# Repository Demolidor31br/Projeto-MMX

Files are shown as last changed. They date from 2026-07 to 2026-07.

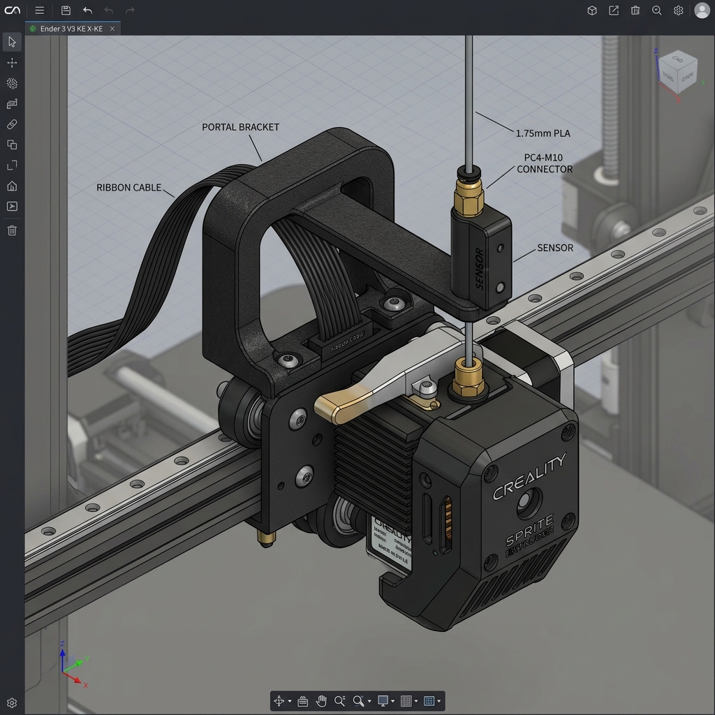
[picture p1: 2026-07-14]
suporte_sensor_montado.jpg

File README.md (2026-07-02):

# Projeto MMX Ender 3 V3 KE

Repositório para o desenvolvimento, configuração e documentação da instalação do sistema **MMX** (Multi-Material Extension / Upgrade) na impressora 3D **Ender 3 V3 KE** (rodando firmware Klipper).

## ⚙️ Especificações Técnicas e Hardware
- **Kit Adquirido:** Trianglelab MMX - **Set B** (Com placa de controle EBB42, sem peças impressas, sem buffer de filamento FV3).
- **Eletrônica de Controle:** Placa **BigTreeTech EBB42** (CAN/USB). Será conectada via USB diretamente no host Klipper (Nebula Pad da Ender 3 V3 KE, que possui root liberado).
- **Software/Firmware:** Ecossistema **Happy Hare** para Klipper (o MMX possui suporte nativo total ao Happy Hare v2/v3).
- **Buffer de Filamento:** Como o kit não acompanha o buffer FV3, usaremos o sistema **Carrot Patch** (ou similar) que serve tanto de suporte de bobinas quanto de buffer passivo, ou fabricaremos um sistema próprio.
- **Peças Impressas:** As peças do MMX precisam ser impressas em ABS/ASA/PETG antes da montagem física na impressora.
- **Montagem Física:** A impressora é uma Creality Ender 3 V3 KE (frame de pórtico padrão, sem perfis 2020 abertos como na Voron). O suporte físico para prender o MMX no topo ou na lateral da KE precisará ser adaptado/desenhado (suporte genérico).

## 🚀 Objetivos do Projeto
- Impressão das peças estruturais do MMX.
- Montagem física e fixação do MMX no pórtico da Ender 3 V3 KE.
- Fiação elétrica da placa EBB42 com a fonte/Nebula Pad.
- Instalação e calibração do **Happy Hare** no Klipper da impressora.
- Configuração de macros de troca de ferramenta (Toolchange) e sensores.

## 👥 Colaboradores
- @Demolidor31br (Criador)
- @cursoscommatheus-oss (Colaborador)

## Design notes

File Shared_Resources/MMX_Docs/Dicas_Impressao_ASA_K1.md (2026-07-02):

# Guia de Calibração e Impressão de ASA na Creality K1

Este guia contém as melhores práticas e calibrações recomendadas para imprimir as peças do **MMX** utilizando filamento **Bambu ASA** na sua **Creality K1** (com CFS).

---

## 1. Parâmetros Adaptados para a K1 no Perfil
O perfil que geramos já leva em consideração as limitações físicas e térmicas da K1 para materiais de alta temperatura (ASA):
- **Limite de Vazão Volumétrica (Max Volumetric Speed):** Limitado em `12 mm³/s`. Embora o bico da K1 consiga derreter até `24 mm³/s` de PLA, o ASA precisa de mais tempo de residência no bloco térmico para derreter de forma homogênea. Limitar a vazão garante que o fatiador nunca force velocidades que causem entupimentos ou peças frágeis.
- **Velocidade de Impressão:** Reduzida para `120 mm/s` (paredes externas) e `150 mm/s` (paredes internas). Velocidades muito altas em ASA diminuem drasticamente a adesão entre camadas, fazendo a peça quebrar fácil. Além disso, velocidades mais baixas garantem **precisão dimensional**, crucial para encaixar os rolamentos, eixos e o servo do MMX.
- **Controle de Ventoinhas:**
  - Ventoinha da Peça (Part Cooling Fan): Mínimo `10%` / Máximo `20%` (apenas para balanços/pontes).
  - Ventoinha Auxiliar Lateral (Aux Fan): **Desligada (0%)**. O fluxo direto dessa ventoinha causaria encolhimento rápido da peça (*warping*) e descolamento da mesa.
  - Ventoinha de Exaustão Traseira: `60%` para filtrar o ar com o filtro de carvão ativado sem resfriar a câmara.

---

## 2. Calibrações Recomendadas (Antes de Iniciar as Peças do MMX)
O Creality Print (por usar a base do OrcaSlicer) possui um menu de **Calibração** no topo. Antes de imprimir as peças finais, recomendamos rodar dois testes simples para o filamento Bambu ASA:

### A. Calibração de Vazão (Flow Rate)
O fluxo padrão está em `0.95` (95%), que é excelente para o ASA. Se quiser a precisão perfeita:
1. No topo do Creality Print, vá em **Calibração** ➔ **Vazão (Flow Rate)**.
2. Siga o Passo 1 (Pass 1) e imprima o padrão.
3. Escolha o quadrado com a superfície mais lisa e ajuste o multiplicador no perfil.

### B. Calibração de Pressure Advance (PA)
O Pressure Advance evita que falte filamento no início de uma linha e que ocorra excesso (cantos arredondados) no final de movimentos rápidos. Para o ASA na K1, o valor ideal costuma ficar entre `0.035` e `0.045`.
1. Vá em **Calibração** ➔ **Pressure Advance**.
2. Selecione a opção **Linha (Line)** ou **Torre (Tower)**.
3. Após a impressão, verifique qual linha ficou mais uniforme nas transições de velocidade e configure o valor no perfil do filamento (seção de Extrusora/Pressure Advance).

---

## 3. Dicas de Ouro para Sucesso com ASA na K1
- **Pré-aquecimento da Câmara (Crucial):** O segredo para o ASA não empenar é a temperatura interna do ar (câmara). Antes de iniciar a impressão, aqueça a mesa a `100 °C` manualmente e deixe a impressora fechada por **10 a 15 minutos**. Isso vai elevar a temperatura da câmara acima de `45-50 °C`, eliminando o risco de trincas (*delamination*).
- **Adesão na Mesa:** Use a mesa de PEI lisa (Smooth PEI) limpa com Álcool Isopropílico. Aplique uma camada fina de cola bastão (ou spray fixador como 3DLac/Karina) para servir de interface de descolamento (o ASA pode grudar demais no PEI e rasgar a chapa ao esfriar, a cola serve como proteção e facilitador de remoção).
- **Suportes:** Algumas peças do MMX possuem balanços. Use suporte do tipo **Tree (Slim)** ou **Normal** com distância Z do suporte de `0.2mm` para facilitar a remoção.

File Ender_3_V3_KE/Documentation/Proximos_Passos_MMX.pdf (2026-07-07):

# PROJETO MMX: MULTI-MATERIAL

## Upgrade de Impressão 3D para Ender 3 V3 KE

## Guia Técnico e Próximos Passos de Execução

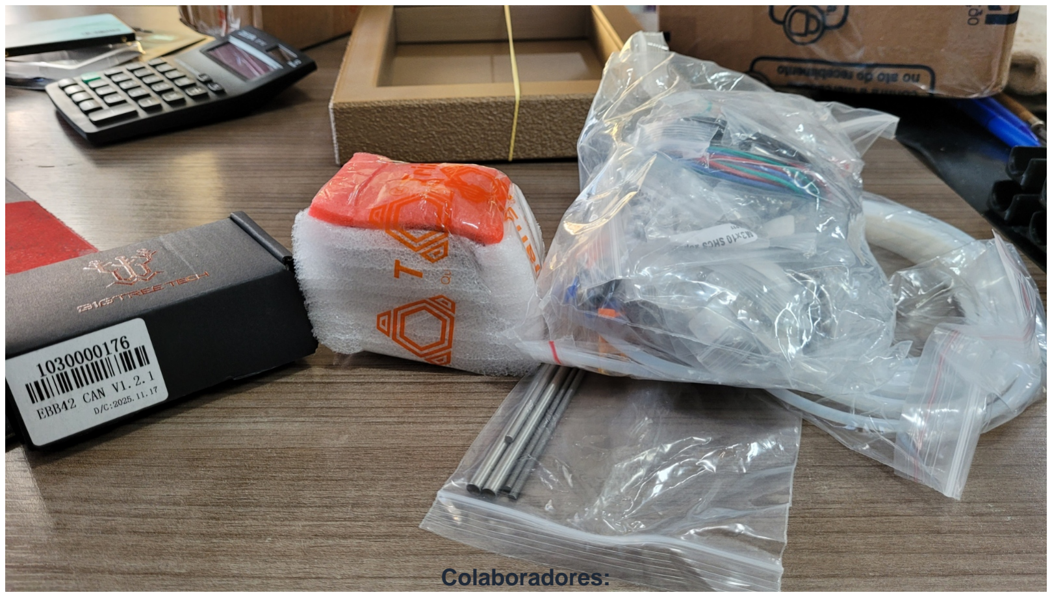
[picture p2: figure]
Colaboradores:

Criador do Projeto: @Demolidor31br Colaborador Técnico: @cursoscommatheus-oss

Gerado em Julho de 2026

Projeto MMX - Ender 3 V3 KE | Guia de Execução | Engenharia & Configuração

## 1. Introdução ao Projeto

Este guia prático foi elaborado para orientar os passos de integração do sistema multicor MMX (Trianglelab Set
B) na impressora Creality Ender 3 V3 KE, utilizando a placa controladora BigTreeTech EBB42 v1.2.1 ligada via USB direta. Com as peças sendo impressas em filamento ASA de alta temperatura na K1, o foco agora muda para o fluxo de montagem mecânica, fiação, compilação de firmware e calibração fina.

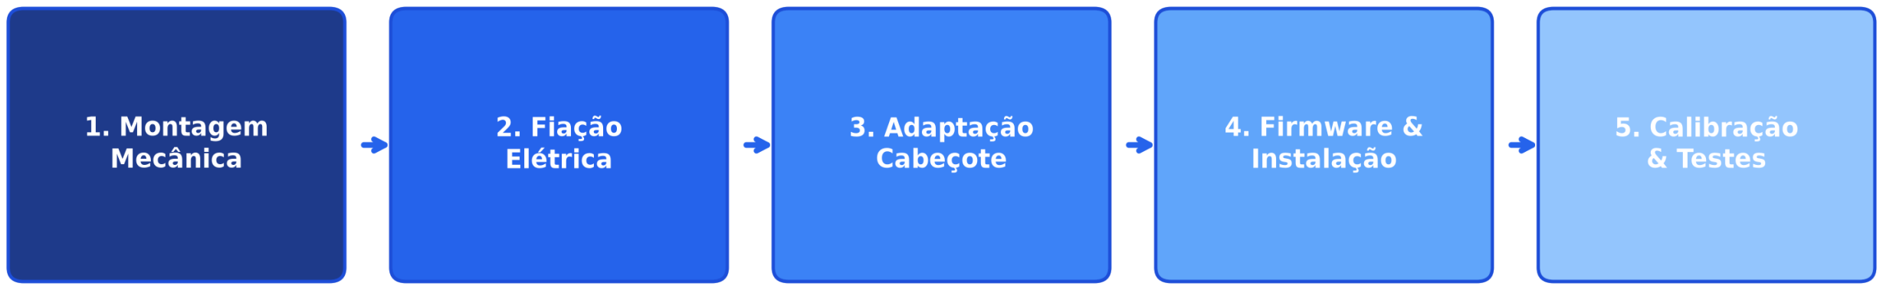
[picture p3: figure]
2. Visão Geral do Fluxo de Trabalho

Abaixo está o roteiro de execução em 5 etapas para colocar o sistema MMX em pleno funcionamento:

[NOTE] Isolamento de Falhas
Siga rigorosamente a ordem proposta. Não avance para a calibração de software sem certificar-se de que a fiação física e a montagem mecânica do seletor de cames estão perfeitas e sem atritos.
Documento de Engenharia - Uso Interno e Colaborativo | Página 2

## 3. Passo 1: Montagem Mecânica do MMX

Após concluir a impressão das peças em ASA/PETG, a montagem física deve seguir esta ordem:

1. Preparação das Laterais: Limpe e lixe rebarbas das peças estruturais (mmx-left-side e mmx-right-side) para garantir encaixes perfeitos.
2. Rolamentos e Eixos: Insira os rolamentos 608 e 625 nos alojamentos correspondentes e monte o eixo de tração central com as engrenagens duplas Bondtech (BMG).
3. Montagem das Idler Doors: Encaixe as 4 portas de pressão dos roletes de filamento (numeradas de 0 a 3). Certifique-se de que cada porta se movimenta livremente sem travar lateralmente.
4. Sistema de Cames e Servo: Monte o eixo de cames (camshaft) com a polia T36 no servo motor e a engrenagem T80 com a correia fechada GT2. O ajuste fino da tensão da correia evita folgas.
5. Gaveta de Eletrônica: Monte a gaveta deslizante na base do MMX para acomodar a placa EBB42 e o step-down de energia.

[WARNING] Folga Dimensional das Portas
Se as portas de pressão (idler doors) apresentarem atrito ao girar em torno do eixo, realize um leve lixamento nas laterais. Elas devem cair livremente sob a força da gravidade.
Documento de Engenharia - Uso Interno e Colaborativo | Página 3

## 4. Passo 2: Fiação Elétrica e Conexões (EBB42 v1.2.1)

A placa EBB42 v1.2.1 ficará oculta na base do MMX e comandará todos os atuadores e sensores. Siga o mapeamento elétrico abaixo para conectar os cabos de forma organizada:

- Motor de Passo Nema 14 (Gear): Conecte na porta de motor (TMC2209).
- Servo Motor (Camshaft): Ligue o fio de sinal de controle (geralmente amarelo/laranja) no pino PB9 da porta Probe.
- Alimentação do Servo: O positivo (V+) e negativo (GND) do servo devem ser alimentados pelo módulo Step-Down ajustado para 5.0V ou 6.0V. O GND do step-down deve ser unificado ao GND da placa EBB42.

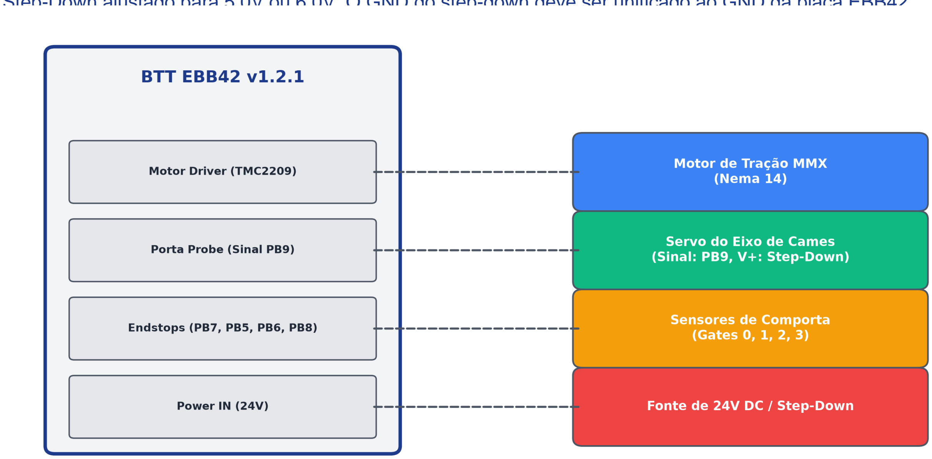
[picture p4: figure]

- Sensores Pre-gate (Portas 0 a 3): Conecte os sensores ópticos de filamento de cada comporta nas portas de endstop (PB7, PB5, PB6 e PB8 respectivamente).

[WARNING] Alimentação do Servo
Nunca alimente o positivo do servo motor diretamente pelo pino de 5V da EBB42. O pico de corrente do servo causará queda de tensão na placa, fazendo o microcontrolador travar e abortar a impressão.
Documento de Engenharia - Uso Interno e Colaborativo | Página 4

## 5. Passo 3: Adaptação do Cabeçote da Ender 3 V3 KE

Como a Ender 3 V3 KE utiliza uma extrusora Direct Drive leve, são necessárias duas modificações físicas:

1. Realocação do Sensor de Filamento: Imprima a nova carcaça do cabeçote e mova o sensor óptico original para ficar posicionado o mais próximo possível das engrenagens de tração. Isso assegura que o Klipper saiba o momento exato em que a ponta do filamento é engatada pela extrusora.
2. Montagem do Y-Splitter: Instale o divisor flutuante (4 entradas para 1 saída) logo acima do sensor realocado. Passe os 4 tubos PTFE Capricorn de diâmetro interno menor (2.0mm) do MMX até as entradas do Y-Splitter.

## 6. Passo 4: Compilação e Instalação do Firmware

1. SSH no Nebula Pad: Conecte via SSH e compile o Klipper para o chip da EBB42:
- Micro-controller: STMicroelectronics STM32
- Processor: STM32G0B1
- Bootloader offset: 8KiB bootloader
- Communication interface: USB (on PA11/PA12)
2. Flash da Placa: Transfira o 'klipper.bin' gerado para o Windows, conecte a placa segurando BOOT e utilize o STM32CubeProgrammer para gravar no endereço 0x08002000.
3. Happy Hare: Clone e execute o script de instalação ('./install.sh'). Escolha o tipo de MMU como 'Ercf' e selecione a placa controladora correspondente 'BTT EBB 42 CANbus v1.2' para mapear os pinos.
Documento de Engenharia - Uso Interno e Colaborativo | Página 5

## 7. Passo 5: Calibração das Macros no Klipper

Com todos os componentes mecânicos e eletrônicos no lugar, faça a calibração de software:

1. Identificação do ID USB:
No SSH da impressora, obtenha o ID do dispositivo USB:
$ ls /dev/serial/by-id/
Copie o ID retornado e configure a seção [mcu mmu] no arquivo mmu_hardware.cfg.
2. Calibração do Seletor (Eixo de Cames):
O Happy Hare precisa saber os ângulos exatos do servo motor para engatar cada canal.
Execute o comando abaixo, alterando X para o ângulo do servo (entre 0 e 180):
$ MMU_CALIBRATE_SELECTOR ANGLE=X SAVE=0
Quando encontrar o ângulo ideal no qual o cames empurra a idler door do canal selecionado e engata a engrenagem, anote e salve nas configurações.
3. Calibração do Feeder (Tração MMX):
Use a macro de calibração para garantir que o motor de passo traciona exatamente 100mm de filamento:
$ MMU_CALIBRATE_GEAR
4. Calibração do Bowden (PTFE):
Calibre a distância percorrida pelo filamento da saída do MMX até a entrada do Y-Splitter:
$ MMU_CALIBRATE_BOWDEN
5. Calibração de Tip Shaping (Formação da Ponta):
Ajuste as velocidades de retração e resfriamento no Happy Hare para moldar a ponta do filamento de modo a não criar fiapos finos que possam causar entupimentos durante a troca de ferramentas.

[NOTE] Apoio da Comunidade
As calibrações de ângulos do eixo de cames do MMX são únicas para cada montagem mecânica. Faça testes com calma em cada canal (0, 1, 2 e 3) antes de rodar impressões de longa duração.
Documento de Engenharia - Uso Interno e Colaborativo | Página 6

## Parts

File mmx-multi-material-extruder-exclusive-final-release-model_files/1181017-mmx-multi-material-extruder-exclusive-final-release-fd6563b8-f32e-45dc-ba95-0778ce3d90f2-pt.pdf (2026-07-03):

MMX Multi-Material Extruder - Manual Traduzido (PT)

# Extrusora Multi-Material MMX

Lançamento Final Exclusivo por Nadir @ CN3D

### 1. Resumo do Projeto

Este documento é a tradução oficial do manual de lançamento da extrusora multi-material MMX (Multi-Material Extruder) desenvolvida pela CN3D. O MMX é um sistema de MMU aberto, projetado para impressoras rodando Klipper, oferecendo alta personalização e suporte de hardware robusto.

Os criadores abriram oficialmente a solicitação de números de série para o MMX OG (versão padrão de 4 cores). Se você montou e colocou em funcionamento, pode registrar o seu número de série oficial no link: http://cn3d.eu/mmxserialrequest

### 2. Histórico de Atualizações de Peças

- 14/07/2025: As portas dos roletes de pressão (idler doors) foram feitas ligeiramente mais estreitas. Isso aumentou a folga de encaixe para evitar travamentos acidentais.
- 16/06/2025: Correção na polia do servo T36 (T36 Servo Pulley) no arquivo CAD. Se você usou a versão antiga do CAD, precisa reimprimir esta polia para ficar alinhada com o eixo de cames (camshaft).
- 12/06/2025: A bandeja inferior (bottom panel) foi atualizada para incluir espaço de encaixe de um módulo regulador de tensão (step down) e a bandeja da placa EBB.
- 03/04/2025: A engrenagem BMG nas portas dos roletes foi levemente recuada para garantir que engate somente quando o canal correspondente (comporta/gate) estiver ativo, evitando que gire em falso.

### 3. Principais Diferenciais do MMX

- Capacidade Personalizável: Embora o projeto padrão venha com 4 comportas (canais 0, 1, 2, 3), o sistema é modular e permite expandir ou reduzir o número de entradas conforme as suas necessidades.
- Confiabilidade Mecânica: Equipado com polias e correias em malha fechada GT2 de alta durabilidade e tensionadores ajustáveis, eliminando folgas e deslizamentos.
- Tração de Filamento Aprimorada: Utiliza engrenagens duplas padrão Bondtech (BMG) para uma pegada firme no filamento e uma alimentação suave.
- Recursos das Comportas: Cada canal possui um sensor de filamento individual e LEDs indicadores de status. Integrado nativamente com as macros do Happy Hare no Klipper, automatiza a carga e descarga sempre que o filamento entra no sensor.
- Modo Carretel Infinito (Endless Spool): Permite carregar várias bobinas do mesmo filamento. O Klipper muda automaticamente para o próximo canal quando o sensor detecta falta de filamento, evitando paradas de impressão tarde da noite.
- Mecânica Avançada de Servo e Cames: O eixo comando de cames (camshaft) é acionado por um servo com relação 36:20. Isso permite girar o eixo até 320 graus com apenas 180 graus de movimento do servo (aproximadamente 50 graus de movimento do servo por canal selecionado).

MMX Multi-Material Extruder - Manual Traduzido (PT)

### 4. Configurações de Impressão Recomendadas

- Materiais:
* Eixo de Cames (camshaft) e Portas dos roletes (idler doors): Imprimir em PLA ou PETG.
* Peças estruturais e carcaça geral: Imprimir em PETG, ABS ou ASA (Recomendado ASA para a K1).
- Altura de Camada: 0.20 mm.
- Perímetros (Walls): 4 voltas de parede.
- Camadas de Topo e Fundo (Top/Bottom): 5 camadas sólidas.
- Preenchimento (Infill): 15% a 20% (Nota de Calibração: Para uso mecânico pesado, a comunidade sugere subir para 40% Gyroid/Giroide).
- Suportes: Usar apenas no Eixo de Cames (camshaft) sob os ressaltos (cames). As portas dos roletes e outras peças planas não precisam de suporte.
- Orientações: Os arquivos STL baixados já estão orientados de fábrica na posição plana de impressão recomendada (separe-os no fatiador antes de organizar).

### 5. Índice de Arquivos do Printset

- Estruturais/Carcaça:
* mmx-left-side.stl / mmx-right-side.stl (Laterais principais)
* mmx-bottom-panel.stl / mmx-back-panel.stl / mmx-front-panel.stl (Painéis inferiores, traseiro e frontal)
- Transmissão/Movimento:
* mmx-camshaft.stl (Eixo comando de cames)
* mmx-t80.stl (Engrenagem T80)
* mmx-t36-servo-pulley.stl (Polia do Servo T36)
- Canais de Entrada (Gates):
* mmx-gate-x4.stl (Comportas de entrada)
* mmx-gate-spacer-x3.stl (Espaçadores entre comportas)
* mmx-idler-door-0, 1, 2, 3.stl (Portas dos roletes numeradas)
- Acessórios/Eletrônica:
* mmx-ebb-42-and-stepdown-slide-tray.stl (Gaveta da EBB42 e Step Down) * mmx-led-defuser-x4.stl (Difusores de LED)

### 6. Licenciamento do Projeto

Este projeto é de código aberto e está licenciado sob a Licença Pública Geral GNU v3.0 (GPL v3.0).
É permitida a criação de remixes, modificações e uso comercial, desde que mantida a atribuição original do autor (Nadir @ CN3D) e compartilhado sob a mesma licença open-source.

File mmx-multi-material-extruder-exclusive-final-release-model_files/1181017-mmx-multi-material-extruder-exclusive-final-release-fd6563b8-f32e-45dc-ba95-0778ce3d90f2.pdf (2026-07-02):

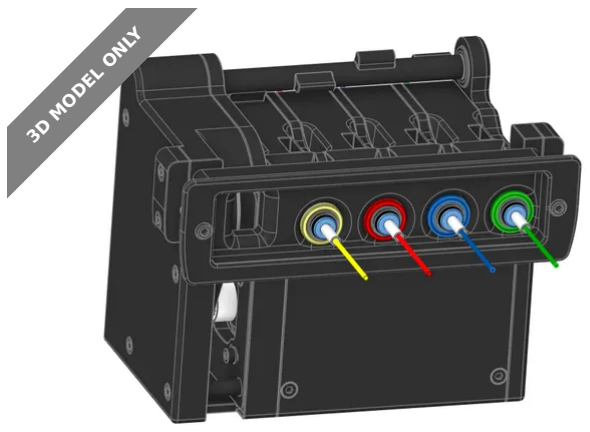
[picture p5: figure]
3D MODEL ONLY

## Summary

Beta release of MMX! Members get 2-week exclusive access. Join our Discord for BOM & updates:

3D Printers (https://printables.com/model?categoryId=1) > Other Printer Parts & Upgrades (https://printables.com/model?categoryId=2)

Tags: | spool | multimaterial | mmu | color | material | multi
prusammu | endless | mmx | pico | infinite | ams | cn3d
picommu | infinitespool | endlessspool | atipicommu

MMX OG — Serial Number Registration Now Open!

We’re officially opening serial number requests for the MMX OG (4-Color) Multi-Material Extruder.
If you’ve built one and made it work — this is your moment to make it official.

Each registered unit will receive a unique MMX Serial Number, as recognition for your work, dedication, and for bringing this community-driven system to life.
Not everyone who started the MMX journey finished it — so if you did, congratulations! You’ve earned your spot in the project’s history.

Nadir @ CN3D (https://printables.com/@Nadir)

## MMX Multi-Material Extruder – Exclusive Final Release

VIEW IN BROWSER (https://printables.com/model/1181017-mmx-multi-material-extruder-exclusive-final-releas)

updated 24. 10. 2025 | published 24. 10. 2025

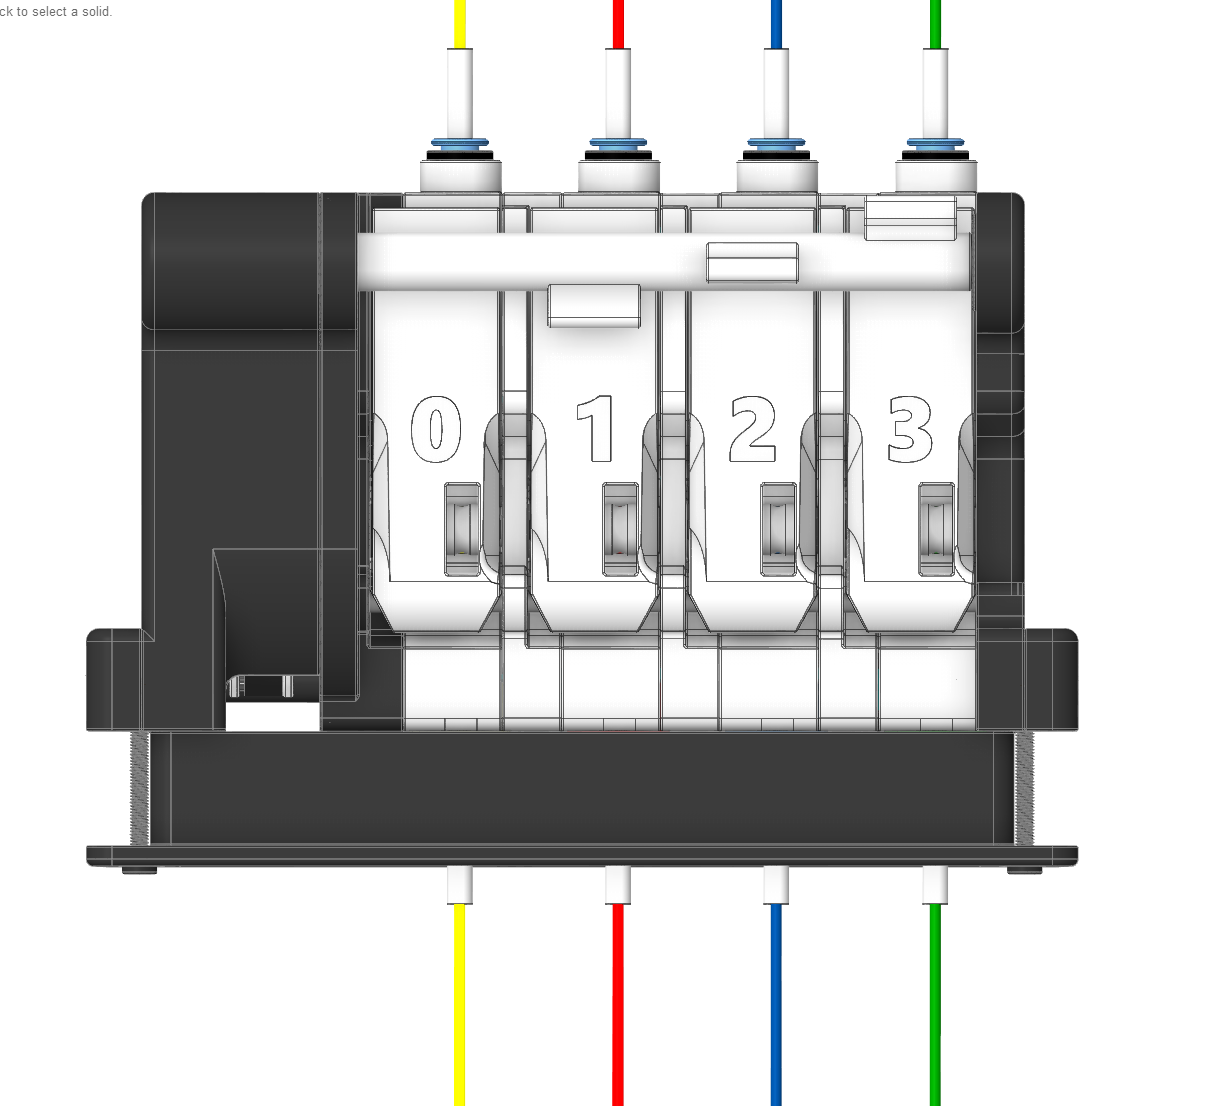
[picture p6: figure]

We have updated the model now the tray has a space for a step down so if you want to have the latest model download and reprint the bottom panel and the ebb tray
12-06-2025
you will need:

Check the download section there is a zip file that includes Orca

Register your build here:
http://cn3d.eu/mmxserialrequest

Thank you for trusting our design and being part of the CN3D community! Together we’re showing the world how far this maker movement can go.

We have made the idler doors a little bit narrow this way we have increased the gap where the idler door sits so it will not catch by mistake. 14-07-2025

We have updated the CAD it was a small err at the T36 Servo Pulley. only if you have used the one from the cad you have to reprint it! 16 - June - 2025
Also update the Right Side Cover.
Thanks to our member azlaeel for pointing this out

We can proudly announce that there is a kit available for purchase. The kit was tested, contains quality components and is all you need to build your MMX. You just have to download the files from here and print them.

The kit does not contain the 3d printed parts.

https://s.click.aliexpress.com/e/_EzjN06s

New update to the Camshaft and to the Idler doors that they are numbered to the specific locations.
also https://github.com/moggieuk/Happy-Hare added the MMX logo to the Mainsail PR and it's part of a new PR for Fluidd

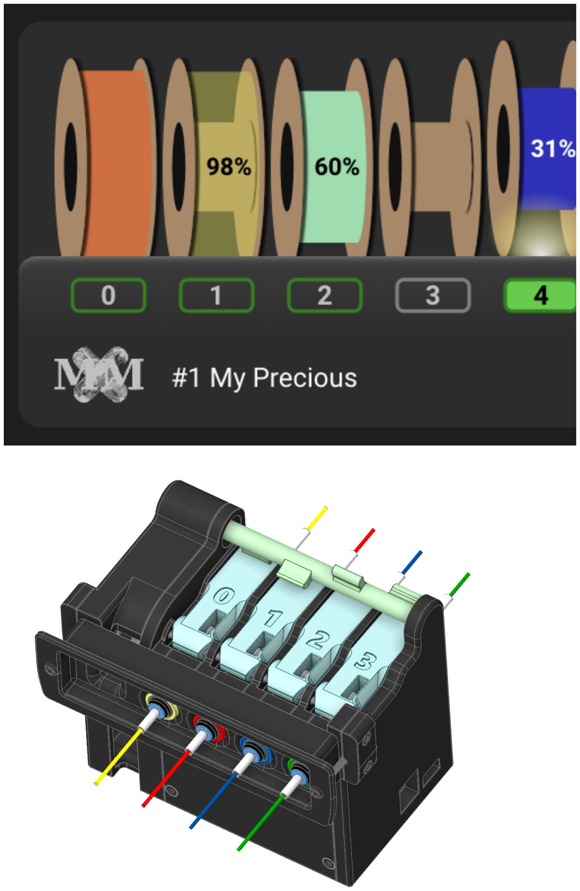
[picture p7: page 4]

Only the camshaft need support the doors don't need

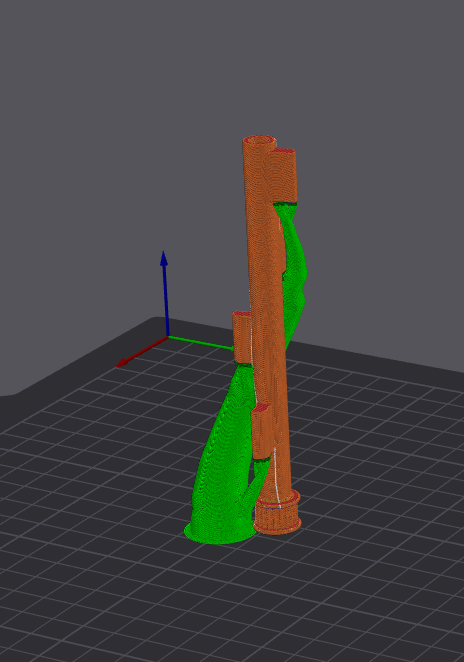
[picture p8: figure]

Today 3 of April I have update the design with a small change the BMG gear in the idler door sit not a little back this way we ensure the will be engaged only when the gate is selected with the previous design it might be caught and allow the bmg to spin even when it was not selected the gear.
We will release soon a full config and also our members are working in parallel to make how to videos in English and Spanish

As a token of appreciation, this will be available exclusively to our members for the first two weeks, after which it will be open to everyone. Thank you for your understanding and for your continued support of our work! (https://www.printables.com/model/1181017-mmx-multi-material-extruder-exclusive-beta-release)

I have update the Cad and also the T36 The servo Pulley to be aligned with the camshaft

I have also uploaded a PDF with the BOM

I have added a 3mf for the Gate that have a support blocker for the filament path.

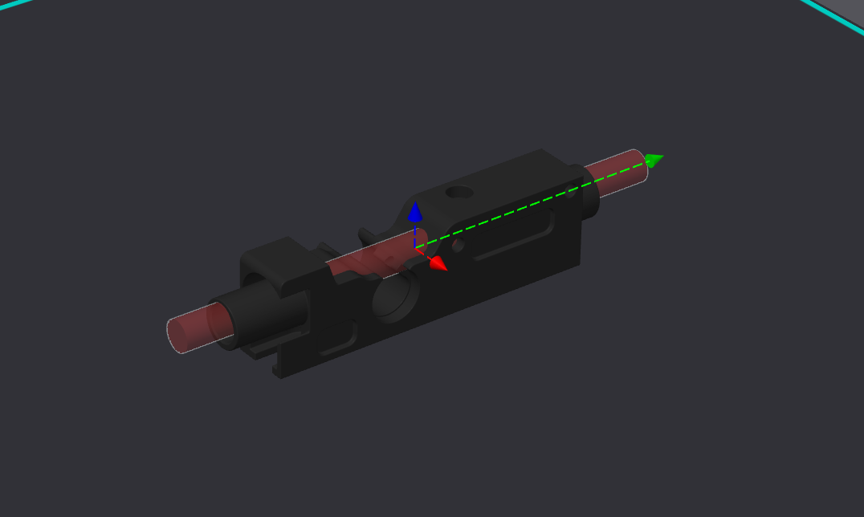
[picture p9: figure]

this way you will not have support on the filament path that is hard to remove.
if we lay it down on a side you will print it with 5 minute faster

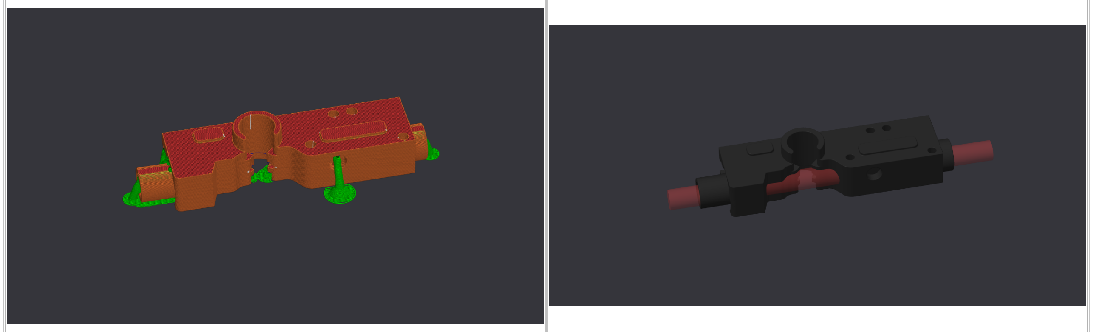
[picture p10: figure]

MMX Multi-Material Extruder

Exciting News: MMX Multi-Material Extruder Development Update! We’re thrilled to share that we are making significant progress on our multi-material system! After evaluating the Pico MMU, we’ve decided to move forward with a completely redesigned concept – one that’s more user-friendly, customizable, and versatile. ---Why MMX Stands Out
Customizable Capacity

Run not just 4 colors or materials, but as many as you want! Increase or decrease the number of inputs based on your needs. but for now we stick to 0-1-2-3 Gates
Reliability Boost

Equipped with GT2 closed-loop belts for enhanced durability. Adjustable tensioning ensures no slippage in the system.
Enhanced Filament Handling

Integrated Bontech dual gears for superior filament grip and smoother guidance.
Multi-Functional Use

Perfect for multi-color or multi-material printing. Supports advanced applications such as:
Gate Features

Each gate features a pre-gate filament sensor and LED indicators.
Thanks to the integration with Happy Hare (special thanks to Moggie for the help!), the system automates sequences when the pre-gate detects filament in, ensuring smooth operation and many more features.

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
Hidden Electronics and Sliding Mechanism

The electronics are neatly hidden in a box with a sliding mechanism for easy access.
Extruder Design

The extruder is based on the Voron V4, a reliable and powerful extruder with an 80:20 gear ratio.
Advanced Servo and Camshaft Mechanics

Gates are engaged by a servo with a 36:20 ratio to the camshaft, allowing the camshaft to rotate 320 degrees even when the servo moves only 180 degrees.
The camshaft is spaced 90 degrees for each lobe from the previous one. This results in 50 degrees of servo movement per operation, thanks to the 1.8:1 ratio between the servo and the camshaft.
Compatibility

Designed to work seamlessly with both direct drive and Bowden setups.
Compatible with any Klipper-based 3D printer. We’ve made a support mount for the SV08, as well as the Xenomorph. Additionally, we’ll be creating support for the V4 toolhead, both of which offer a filament sensor in the toolhead and a filament cutter.
Advanced Hub Options

Developed a 4-lane hub.
Also offering a 4-in-1 hub featuring an integrated Klinky encoder.
Redesigned from Scratch

This version combines multiple innovative ideas into one cohesive design, with the entire kit redesigned from scratch for optimal performance.
Section in Happy Hare

In Happy Hare, you can find this system under Section 9: PicoMMU, with our default cam spacing and design parameters included.

---Introducing the MMXThe MMX Multi-Material Extruder is a cutting-edge solution designed for both hobbyists and professionals. We’re

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
collaborating with Happy Hare to ensure smooth integration with their ecosystem. Expect an easy step-by-step installation guide! ---

Using PETG for PLA or ABS for supports.
Infinite Spool Mode: Load multiple spools of the same material. The system will automatically switch when one spool ends or breaks, eliminating late-night spool monitoring!
Additional Notes:

Mounting Compatibility: Tested with Xenomorph Orbiter (https://www.printables.com/model/1114702-xenomorph-orbiter-toolhead) & V4 (https://www.printables.com/model/1133951-v4-toolhead-ideal-for-mmu-for-sv08-and-any-voron-g) toolheads (both support filament sensor & cutter)
Software Recommendation: Happy Hare (https://github.com/moggieuk/Happy-Hare) for seamless MMU integration
Beta Status: Still in beta, improvements ongoing!
Upcoming Video: Assembly & setup guide in progress
Print Settings:

Material Recommendations:
PLA or PETG for camshaft & idler doors PETG or ABS for other components Orientation: Pre-oriented files provided Layer Height: 0.2mm
Walls: 4
TOP/Bottom: 5
Infill: 15-20
Supports: Minimal (as needed)

Please join the discord for BOM and More! https://discord.gg/SJu43FjcuF

## This remix is based on

GitHub - VoronDesign/Mobius-Extruder: Extruder for the Voron line of Printers (https://github.com/VoronDesign/Mobius-Extruder)

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
## Model files

- CAD | 1 file
- Updated 24/October/2025

sv08-mmx-alpha-by-cn3d.stp

mmx-right-side-cover-spacer-x4.stl

mmx-camshaft-spacer.stl

mmx-back-panel.stl

mmx-led-defuser-x4.stl

mmx-servo-idler.stl

mmx-front-panel.stl

mmx-gate-spacer-x3.stl

- updated
- 4/20
- updated 16-June-2025
- updated 16-June-2025
- Updated 12-jully-2025

mmx-left-side.stl

mmx-servo-and-extruder-holder.stl

right-ear.stl

left-ear.stl

sv08-mmx-tophat-grile.stl

mmx-camshaft.stl

mmx-t80.stl

mmx-t36-servo-pulley.stl

mmx-right-side.stl

mmx-bottom-panel.stl

## Other files

- Updated 12-jully-2025
- Updated 14-jully-2025
- Updated 14-jully-2025
- Updated 14-jully-2025
- Updated 14-jully-2025
- updated 24-october-2025
- updated 24-october-2025
- Sovol SV08 Orca Profile | 1 file

mmx-ebb-42-and-stepdown-slide-tray.stl

mmx-idler-door-1.stl

mmx-idler-door-3.stl

mmx-idler-door-0.stl

mmx-idler-door-2.stl

mmx-gate-x4.stl

gate-x4.3mf

sovol-sv08-orca-profile-for-mmx.zip

- Amazon Affiliate links
- made by 3dpo

## License

This work is licensed under a GNU

General Public License v3.0 (https://www.gnu.org/licenses/gpl-3.0.html)

✖ | Sharing without ATTRIBUTION
✔ | Remix Culture allowed
✔ | Commercial Use
✔ | Meets Open Definition
ℹ | Share under the same license

mmx-bom.pdf

mmx-bom-worldwide.pdf

mmx-user-manual-24-05-2025.pdf

GNU
General
Public
License
v3.0 (https://www.gnu.org/licenses/gpl-3.0.html)

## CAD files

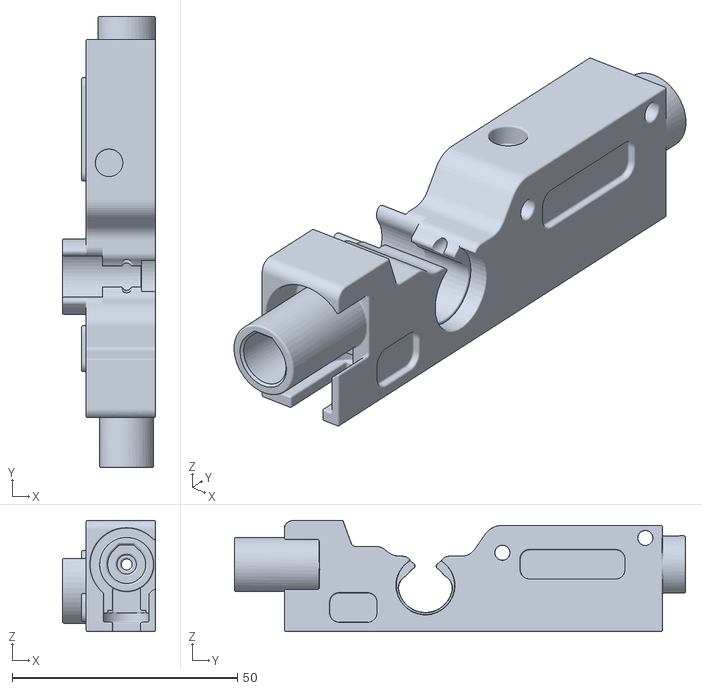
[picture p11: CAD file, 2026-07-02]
mmx-multi-material-extruder-exclusive-final-release-model_files/mmx-gate-x4.stl
20.7 x 100.1 x 24.7

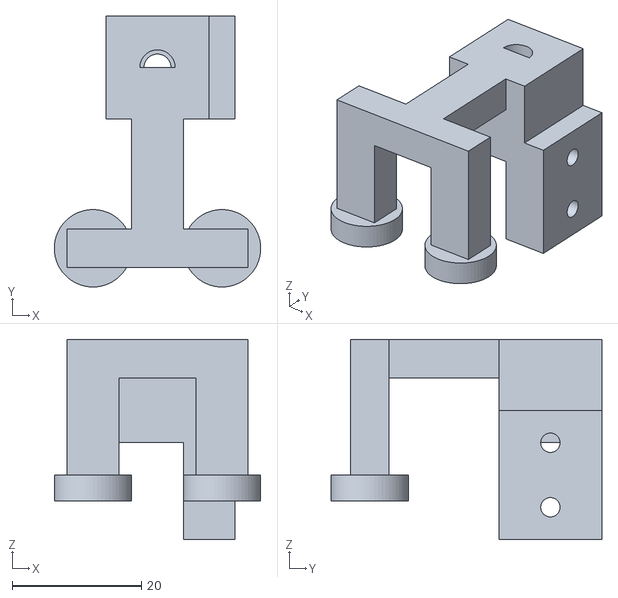
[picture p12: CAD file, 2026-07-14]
suporte_sensor_ke.stl
32.0 x 42.0 x 31.0

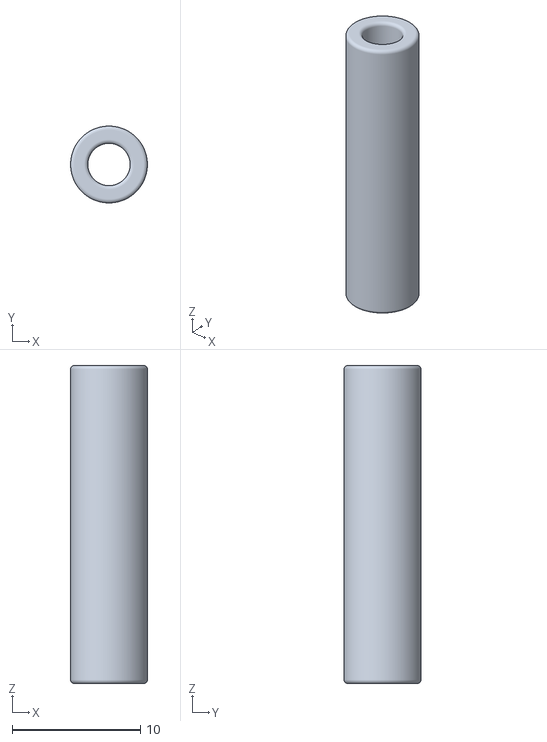
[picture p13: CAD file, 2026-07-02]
mmx-multi-material-extruder-exclusive-final-release-model_files/mmx-right-side-cover-spacer-x4.stl
6.00 x 6.00 x 24.8

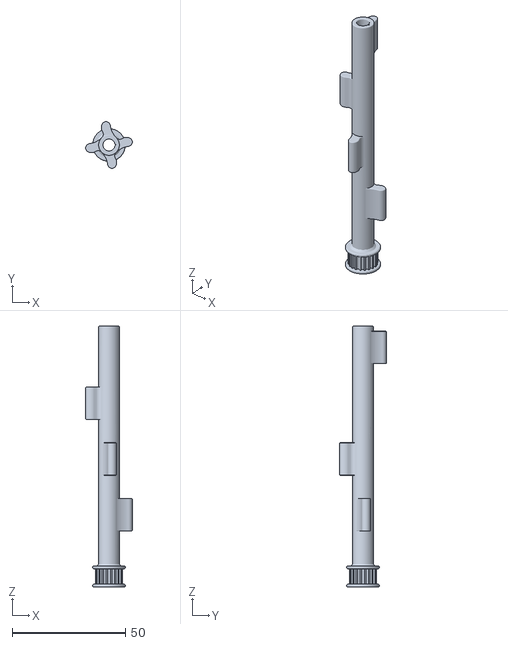
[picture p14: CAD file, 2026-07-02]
mmx-multi-material-extruder-exclusive-final-release-model_files/mmx-camshaft.stl
20.7 x 20.7 x 115.5

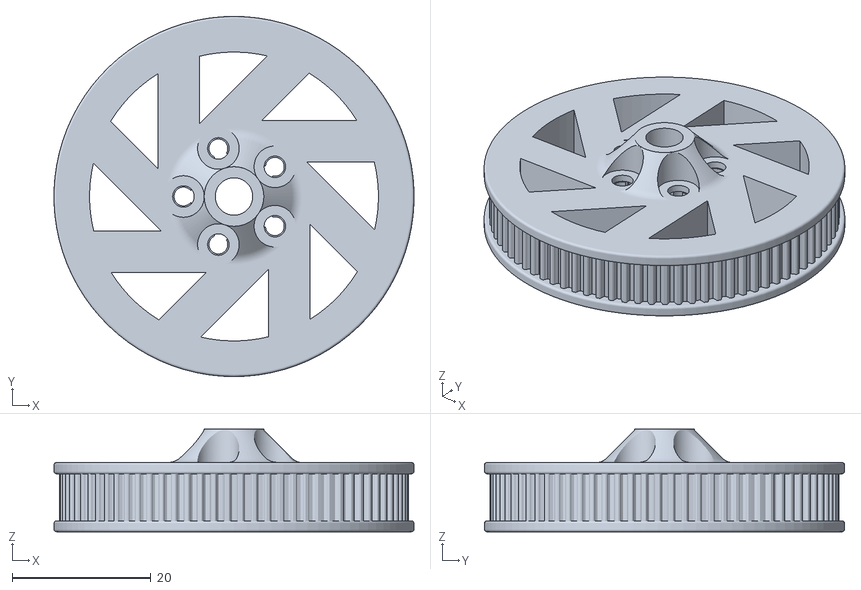
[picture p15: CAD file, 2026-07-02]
mmx-multi-material-extruder-exclusive-final-release-model_files/mmx-t80.stl
52.0 x 52.0 x 14.8

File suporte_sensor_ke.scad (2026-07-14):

// Suporte do Sensor de Filamento no Cabeçote - Ender 3 V3 KE para MMX
// Modelado parametricamente em formato de "Portal" para desviar do cabo flat
// Criado por Antigravity AI

$fn = 60;

// ==========================================
// VARIÁVEIS PARAMÉTRICAS (Altere aqui se precisar ajustar)
// ==========================================
screw_spacing = 20;     // Distância de centro a centro dos parafusos traseiros (mm)
tunnel_height = 25;     // Altura vertical livre para o cabo flat passar por dentro (mm)
reach_distance = 28;    // Avanço horizontal (Y) até a entrada de latão da extrusora (mm)
base_thickness = 4;     // Espessura da base nos furos (mm)
pilar_width = 8;        // Largura dos pilares laterais (mm)
pilar_thickness = 6;    // Espessura dos pilares laterais (mm)
arm_thickness = 6;      // Espessura do braço horizontal (mm)
ptfe_thread_d = 5.5;    // Diâmetro do furo para rosca M6 do conector pneumático (mm)
sensor_screw_d = 3.0;   // Diâmetro do furo de parafuso do sensor da KE (mm)

// ==========================================
// MÓDULOS DE CONSTRUÇÃO
// ==========================================

module base_furo(pos_x) {
    translate([pos_x, 0, 0]) {
        difference() {
            cylinder(d=pilar_width + 4, h=base_thickness);
            translate([0, 0, -1])
                cylinder(d=3.2, h=base_thickness + 2); // Furo M3 passante
        }
    }
}

module pilar(pos_x) {
    translate([pos_x - pilar_width/2, -pilar_thickness/2, 0]) {
        cube([pilar_width, pilar_thickness, tunnel_height]);
    }
}

module portal() {
    // Bases com furos
    base_furo(-screw_spacing/2);
    base_furo(screw_spacing/2);
    
    // Pilares que sobem de cada parafuso
    pilar(-screw_spacing/2);
    pilar(screw_spacing/2);
    
    // Travessa superior que une os pilares
    translate([-screw_spacing/2 - pilar_width/2, -pilar_thickness/2, tunnel_height - arm_thickness]) {
        cube([screw_spacing + pilar_width, pilar_thickness, arm_thickness]);
    }
}

module braco_e_cabeca() {
    // Braço horizontal que vai de Y=0 até reach_distance
    translate([-pilar_width/2, -pilar_thickness/2, tunnel_height - arm_thickness]) {
        cube([pilar_width, reach_distance + pilar_thickness/2, arm_thickness]);
    }
    
    // Cabeça do sensor (no final do braço)
    translate([0, reach_distance, tunnel_height - arm_thickness]) {
        difference() {
            // Bloco principal da cabeça
            translate([-8, -8, -10])
                cube([16, 16, 10 + arm_thickness]);
            
            // Furo vertical passante para o filamento (4.2mm)
            translate([0, 0, -11])
                cylinder(d=4.2, h=25);
            
            // Furo rosqueável M6 no topo para o conector pneumático PTFE
            translate([0, 0, arm_thickness - 6])
                cylinder(d=ptfe_thread_d, h=7);
        }
        
        // Aba lateral para prender o sensor original da KE
        // O sensor da KE é parafusado na lateral (eixo X)
        translate([8, -8, -25]) {
            difference() {
                // Corpo da aba
                cube([4, 16, 20]);
                
                // Dois furos de ajuste de altura para o parafuso M3 do sensor
                translate([-1, 8, 5])
                    rotate([0, 90, 0])
                        cylinder(d=sensor_screw_d, h=6);
                translate([-1, 8, 15])
                    rotate([0, 90, 0])
                        cylinder(d=sensor_screw_d, h=6);
            }
        }
        
        // Ombro/Guia traseira para travar o sensor e impedir que ele gire
        translate([4, -8, -25]) {
            cube([4, 4, 15]);
        }
    }
}

// ==========================================
// MONTAGEM FINAL
// ==========================================
union() {
    portal();
    braco_e_cabeca();
}

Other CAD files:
mmx-multi-material-extruder-exclusive-final-release-model_files/gate-x4.3mf

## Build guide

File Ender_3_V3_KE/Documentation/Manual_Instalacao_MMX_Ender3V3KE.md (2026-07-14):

# 📘 Manual de Engenharia: Integração MMX (Trianglelab) na Ender 3 V3 KE

Este documento descreve detalhadamente todos os passos físicos, elétricos e de software para instalar o Sistema MMX (4 Cores) na Creality Ender 3 V3 KE, controlando-o através de uma placa externa **BTT EBB42 v1.2.1** e do ecossistema Happy Hare.

> [!IMPORTANT]
> **Aviso de Engenharia:** Este procedimento envolve modificações críticas na estrutura física e no firmware da impressora. Siga a ordem estabelecida para garantir o isolamento de falhas durante a calibração.

---

## 🏗️ 1. Arquitetura do Sistema

O diagrama abaixo ilustra como os componentes de Hardware e Software se comunicam na nossa topologia customizada utilizando a placa EBB42 em modo USB direto:

```mermaid
graph TD
    subgraph Impressora ["Ender 3 V3 KE"]
        A[Placa Mãe Original / Nebula Pad] -->|Comunicação Interna| B(Klipper / Moonraker)
        C[Extrusora Direct Drive]
        D[Sensor Fim de Filamento Modificado]
    end

    subgraph Hub ["Comunicação Externa"]
        E[Hub USB Externo Alimentado]
    end

    subgraph MMX_System ["Sistema MMX (Trianglelab)"]
        F[Placa BTT EBB42 v1.2.1 - STM32G0B1]
        G[MMX Camshaft & Feeder]
        H[Buffer Carrot Patch]
    end

    B <-->|Cabo USB| E
    E <-->|Cabo USB Tipo-C| F
    F -->|Cabo do Motor / Servo / Endstops| G
    G -->|Filamento via PTFE| H
    G -->|Tubo PTFE| C
    D -->|Sinal Físico| A
```

---

## 🔗 2. Lista de Materiais (BOM) e Links Essenciais

### Hardware & Eletrônica
*   **Impressora:** Creality Ender 3 V3 KE
*   **Sistema Multicor:** [Trianglelab MMX (Set B - 4 Cores)](https://github.com/trianglelab/MMX)
*   **Placa Controladora:** [BigTreeTech EBB42 v1.2.1 (Extruder Board)](https://github.com/bigtreetech/EBB)
*   **Hub USB:** Recomendado Hub USB com alimentação externa ligado na tela Nebula Pad para evitar quedas de tensão na conexão de dados da EBB42 e da impressora.
*   **Alimentação Externa:** Fonte de 24V DC (mínimo 3A) para alimentar a placa EBB42 e os motores/servos.
*   **Módulo Step-Down (DC-DC):** Regulador de tensão (24V para 5V ou 6V) dedicado para alimentar o servo motor do eixo de cames (*camshaft*).
    > [!WARNING]
    > **Aviso de Sobrecarga:** Não alimente o servo diretamente pela saída de 5V da EBB42. O pico de corrente do servo durante as trocas de canal pode queimar o regulador de tensão interno da placa ou causar travamentos no MCU. Utilize o step-down externo.
*   **Tubos PTFE:** Tubos Capricorn ou similares de baixa fricção (diâmetro interno de 2.0mm a 2.5mm).

### Modelos 3D (Pré-requisitos a serem impressos)
*   **Y-Splitter (4 em 1):** Divisor flutuante a ser montado acima do *Direct Drive*.
*   **Carcaça do Toolhead Customizada:** Peça desenhada no Solid Edge para abrigar e realocar o sensor de filamento original para dentro do bloco da extrusora.
*   **Buffer Carrot Patch:** Para armazenar de forma segura o filamento que sofre recuo (*unload*) durante a troca de cores.
*   **Bandeja Inferior Customizada:** Gaveta integrada para acomodar a EBB42 e o step-down ([mmx-ebb-42-and-stepdown-slide-tray.stl](file:///G:/Meu%20Drive/MMX-Ender%203/mmx-multi-material-extruder-exclusive-final-release-model_files/mmx-ebb-42-and-stepdown-slide-tray.stl)).

### Softwares e Scripts Úteis
*   [Guilouz Creality Helper Script](https://github.com/Guilouz/Creality-Helper-Script): Script base para fazer o "Root" seguro do Creality OS.
*   [Happy Hare (V2/V3)](https://github.com/moggieuk/Happy-Hare): O principal ecossistema e firmware do Klipper para controle de MMUs e troca de filamentos.

---

## 💻 3. Preparação do Software da Ender 3 V3 KE (Root)

A KE de fábrica roda um sistema bloqueado (Creality OS). O primeiro passo real é "libertar" a impressora para termos acesso total ao Klipper.

### Passo 3.1: Habilitar o Root no Display
1. Ligue a KE e garanta que ela está na rede Wi-Fi.
2. Anote o endereço IP (ex: `192.168.1.15`).
3. Vá em **Configurações (Settings) > Rede (Network)**, role a tela e selecione **Root**.
4. Aceite os termos (demora cerca de 30 segundos).
    > [!NOTE]
    > **Senha de Root:** A senha padrão varia conforme a versão do firmware da KE. Tente `creality` (tudo minúsculo). Se não funcionar, tente `Creality2023` (C maiúsculo, com o ano). A senha correta também aparece na tela da impressora ao habilitar o root.

### Passo 3.2: Acesso SSH e Instalação do Klipper Limpo
1. No seu PC Windows, abra o PowerShell ou o PuTTY.
2. Digite o comando SSH:
   ```bash
   ssh root@<IP_DA_IMPRESSORA>
   ```
3. Use a senha exibida na tela da impressora (geralmente `creality` ou `Creality2023`).
4. Instale o Script do Guilouz:
   ```bash
   git clone https://github.com/Guilouz/Creality-Helper-Script.git /usr/data/helper-script
   sh /usr/data/helper-script/helper.sh
   ```
5. Dentro do menu do script (Menu `1 - Install`), instale:
   *   **Mainsail** e/ou **Fluidd** (Interface Gráfica)
   *   **Moonraker** (A API do Klipper)
   *   **Entware** (Necessário para baixar pacotes extras)

> [!TIP]
> Após finalizar, digite o IP da impressora no navegador. A interface do Mainsail deve aparecer, dando controle total aos arquivos `printer.cfg`.

---

## ⚡ 4. Preparação da Placa Externa (BTT EBB42 v1.2.1)

O MMX será comandado pela placa BTT EBB42 v1.2.1 conectada via USB diretamente à impressora.

### Passo 4.1: Compilar o Firmware no Klipper
No SSH da impressora, compile o Klipper para o processador STM32G0B1:
```bash
cd ~/klipper
make menuconfig
```
Use as seguintes opções na tela azul:
*   **Micro-controller Architecture:** `STMicroelectronics STM32`
*   **Processor model:** `STM32G0B1`
*   **Bootloader offset:** `8KiB bootloader` (Offset padrão para placas BTT EBB42)
*   **Clock Reference:** `8 MHz crystal`
*   **Communication interface:** `USB (on PA11/PA12)`

Salve pressionando `Q` e confirmando com `Y`. Em seguida, compile o arquivo:
```bash
make clean
make
```
O arquivo gerado estará em `~/klipper/out/klipper.bin`.

### Passo 4.2: Gravar o Firmware na Placa (Flash)
1. Use um programa como WinSCP para transferir o arquivo `klipper.bin` para o Windows.
2. Conecte a placa BTT EBB42 via cabo USB Tipo-C ao PC, **segurando o botão físico BOOT** da placa para entrar no modo DFU.
3. Utilize o software **STM32CubeProgrammer**:
   * Selecione a interface de conexão como **USB**.
   * Clique em **Connect** (a placa deve ser reconhecida como um dispositivo DFU).
   * Carregue o arquivo `klipper.bin`.
   * Configure o endereço de gravação (Start Address) como `0x08002000` (correspondente ao offset de 8KiB).
   * Clique em **Start Programming**. Após terminar, desconecte a placa.

---

## 🐰 5. Instalação do Happy Hare

Com o Root feito e a placa pronta, instalamos o software de gerenciamento de trocas de filamento.
Pelo SSH da impressora, execute:
```bash
cd ~
git clone https://github.com/moggieuk/Happy-Hare.git
cd Happy-Hare
./install.sh -i
```

No instalador interativo:
*   **Escolha o Tipo de MMU:** Procure por **`MMX`** na lista. Se a sua versão do Happy Hare não listar o MMX explicitamente, selecione **`Ercf`** como fallback (a lógica de controle é compatível).
*   **Nome do MCU:** `mmu`
*   **Tipo da Placa Controladora:** Escolha a opção **`BTT EBB 42 CANbus v1.2 (for MMX or Pico)`**. 
    > [!NOTE]
    > Mesmo que estejamos conectando a placa via USB físico direto, esta opção é necessária para carregar automaticamente a biblioteca de mapeamento de pinos correta da EBB42 para o MMX.

O sistema instalará as dependências e criará os arquivos de configuração na pasta `mmu/`.

### Passo 5.1: Incluir o Happy Hare no Klipper
Após a instalação, abra o arquivo `printer.cfg` pela interface do Mainsail (ou via SSH) e adicione a seguinte linha **no final do arquivo**:
```ini
[include mmu/base/*.cfg]
```
Salve o arquivo e reinicie o firmware com `FIRMWARE_RESTART`. Sem essa linha, o Klipper não reconhecerá o sistema MMU.

---

## 🛠️ 6. Modificações de Hardware (Y-Splitter e Sensor)

Como a Ender 3 V3 KE é uma impressora *Direct Drive* (extrusora montada no cabeçote móvel), precisamos de duas peças personalizadas:

1. **Sensor de Visão de Raio-X:** A nova carcaça do cabeçote realoca o sensor óptico de filamento original para ficar o mais próximo possível das engrenagens de tração da extrusora. Isso indica ao Klipper o instante exato em que a ponta entra na zona de *grip*.
2. **Y-Splitter:** Uma peça com 4 entradas de PTFE (uma vinda de cada comporta do MMX) e 1 saída acoplada logo acima desse sensor do cabeçote.

---

## 🔋 7. Alimentação de Energia (24V para o MMX)

A placa EBB42 e o motor de tração do MMX precisam de **24V DC** para funcionar. O servo motor precisa de **5V ou 6V** (fornecidos pelo módulo step-down). Existem duas formas de obter essa alimentação:

### Opção A: Usar a fonte interna da Ender 3 V3 KE (Recomendado)
A fonte original da impressora já é de 24V e possui corrente de sobra para alimentar o MMX (consumo adicional de ~1A a 2A).
1. Desligue a impressora da tomada.
2. Abra a tampa plástica inferior da base da KE para acessar a fonte de alimentação.
3. Identifique os bornes de saída (`V+` e `V-`/`GND`).
4. Insira um par de fios novos (cabo de 1.0mm² ou 1.5mm², ~1.5m de comprimento) nos mesmos bornes de parafuso (positivo no `V+`, negativo no `V-`), junto com os fios que já estão lá. Aperte bem.
5. Passe esse cabo para fora da carcaça e leve-o até a base do MMX.

### Opção B: Fonte externa dedicada
Se preferir não abrir a carcaça da impressora:
*   Use uma fonte de **24V DC com pelo menos 2A a 3A** (tipo carregador de notebook ou fonte colmeia pequena).
*   Conecte os fios de saída diretamente nos bornes de energia da EBB42 e no step-down.

### Esquema de Ligação
1. **EBB42:** Conecte `V+` (24V) e `V-` (GND) nos bornes de parafuso de energia da placa. Isso alimenta a placa e o motor de passo (Nema 14) automaticamente.
2. **Step-Down:** Conecte `IN+` e `IN-` em paralelo com a entrada de 24V da EBB42. Ajuste a saída para **5.0V ou 6.0V** com um multímetro antes de conectar o servo.
3. **Servo:** Conecte o fio vermelho (V+) no `OUT+` do step-down, o fio marrom/preto (GND) no `OUT-`, e o fio de sinal (amarelo/laranja) no pino **PB9** da porta Probe da EBB42. Unifique o GND do step-down com o GND da porta Probe para referência de sinal estável.

---

## 🔌 8. Diagrama de Cabeamento BTT EBB42 <-> MMX

As conexões elétricas nos pinos da EBB42 v1.2.1 seguirão o mapeamento abaixo:

```mermaid
graph LR
    subgraph BTT_EBB42 ["BTT EBB42 v1.2.1 (Portas)"]
        MOT[Driver do Motor / MOT]
        PROBE[Porta Probe / BLTouch]
        ENDSTOPS[Portas de Sensor / Endstop]
        RGB[Porta RGB / LED]
        PWR[Power IN 24V]
        USB[USB Type-C]
    end
    
    subgraph MMX ["Hardware MMX"]
        P1(Motor de Tração/Gear)
        P2(Servo do Eixo de Cames)
        S0(Sensor do Canal 0 / Gate 0)
        S1(Sensor do Canal 1 / Gate 1)
        S2(Sensor do Canal 2 / Gate 2)
        S3(Sensor do Canal 3 / Gate 3)
    end
    
    MOT --- P1
    PROBE -->|Sinal PB9| P2
    ENDSTOPS -->|Pino PB7| S0
    ENDSTOPS -->|Pino PB5| S1
    ENDSTOPS -->|Pino PB6| S2
    ENDSTOPS -->|Pino PB8| S3
```

### Mapeamento Detalhado de Pinos no Klipper
*   **Motor de Passo (Gear/Feeder):** Conectado à porta de motor da EBB42.
    *   `step_pin: mmu:PD0`
    *   `dir_pin: mmu:!PD1` (verifique a direção de rotação e retire o `!` se necessário)
    *   `enable_pin: mmu:!PD2`
    *   `uart_pin: mmu:PA15` (driver TMC2209 integrado)
*   **Servo Motor (Eixo de Cames/Camshaft):** Fio de sinal conectado ao pino **`mmu:PB9`** (pino de controle da porta Probe/BLTouch).
    *   *Lembrete:* Alimente o positivo e negativo do servo através do step-down regulado a 5V/6V, compartilhando o terra (GND) com a placa.
    > [!WARNING]
    > **Atenção sobre PB9 e CAN Bus:** Os pinos PB8 e PB9 do chip STM32G0B1 são os pinos físicos do barramento CAN (CAN_TX/CAN_RX). Eles **só ficam livres como GPIO** quando o firmware é compilado para comunicação **USB (on PA11/PA12)**, que é o nosso caso. Se no futuro vocês migrarem para comunicação CAN Bus, o servo precisará ser realocado para outro pino livre.
*   **Sensores Fim de Curso de Entrada (Gates 0 a 3):**
    *   **Gate 0 (Canal 0):** `mmu:PB7`
    *   **Gate 1 (Canal 1):** `mmu:PB5`
    *   **Gate 2 (Canal 2):** `mmu:PB6`
    *   **Gate 3 (Canal 3):** `mmu:PB8`
*   **LED de Status RGB (Opcional):** Conectado na porta RGB da placa (pino `mmu:PD3`).

---

## ⚙️ 9. Ajuste de Configurações das Macros no Klipper

No arquivo `mmu_parameters.cfg` gerado pelo Happy Hare, configure as distâncias físicas e controle da ponta do filamento (*Tip Shaping*):

```ini
[mmu]
# A distância exata entre o sensor realocado no cabeçote e o bico (medido na prática).
toolhead_sensor_to_nozzle: 45.0

# Obriga o Klipper a fazer o recuo e esfriar o filamento
# para moldar a ponta sem formar fiapos antes de puxar de volta pro buffer.
force_form_tip_standalone: True
```

No arquivo `mmu_hardware.cfg`, configure a declaração da placa e os pinos do motor e sensores:

```ini
[mcu mmu]
serial: /dev/serial/by-id/usb-Klipper_stm32g0b1xx_...-if00 # Substitua pelo ID real obtido via SSH

[tmc2209 manual_stepper gear_stepper]
uart_pin: mmu:PA15
run_current: 0.800
hold_current: 0.100

[manual_stepper gear_stepper]
step_pin: mmu:PD0
dir_pin: !mmu:PD1
enable_pin: !mmu:PD2
# ... (demais configurações de velocidade/passos padrão do MMX)

[servo mmu_servo]
pin: mmu:PB9
maximum_servo_angle: 180
minimum_pulse_width: 0.0005
maximum_pulse_width: 0.0025

# Mapeamento dos sensores de entrada (pre-gate)
# Verifique o formato exato na versão do Happy Hare instalada
gate_sensor_pins: mmu:PB7, mmu:PB5, mmu:PB6, mmu:PB8
```

---

## 🏁 10. Calibração e Fluxo Final

A ordem oficial de calibração ao energizar o sistema é:

1.  **Descobrir o ID da EBB42:** Conecte a placa no USB do Nebula Pad, acesse via SSH, rode o comando abaixo e insira o ID resultante no `mmu_hardware.cfg`:
    ```bash
    ls /dev/serial/by-id/
    ```
2.  **Calibrar o Seletor de Cames (`MMU_CALIBRATE_SELECTOR`):**
    Como o MMX não usa uma chave limite linear física (endstop) para selecionar as portas (ele usa o eixo de cames rotativo acionado por servo), você deve achar os ângulos do servo para cada canal (0, 1, 2 e 3).
    *   Rode o comando: `MMU_CALIBRATE_SELECTOR ANGLE=X SAVE=0` para testar os ângulos individuais de cada canal até que o ressalto do cames empurre perfeitamente o rolete de pressão do respectivo canal contra a engrenagem tracionadora.
3.  **Calibrar o Feeder (`MMU_CALIBRATE_GEAR`):** Ajusta os passos por milímetro do motor de tração do MMX para empurrar a quantidade exata de filamento demandada.
4.  **Calibrar o Bowden (`MMU_CALIBRATE_BOWDEN`):** Mede o comprimento exato dos tubos PTFE que ligam cada comporta do MMX até o Y-Splitter flutuante no cabeçote.
5.  **Ajuste Fino de Ponta (Tip Shaping):** Realiza testes repetidos de carga e descarga para configurar a temperatura ideal de retração e evitar a formação de fiapos ("cabelo de anjo") no filamento recuado.

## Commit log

2026-07-02 Add STL printset models and Klipper documentation for MMX
    [gate-x4.3mf, mmx-camshaft.stl, mmx-gate-x4.stl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]
2026-07-02 Add Creality Print 5.0 Bambu ASA and K1 process profiles for MMX
2026-07-02 Add Creality Print 7.0 user profiles for projeto-mmx
2026-07-02 Update slicer profiles to use Creality Print 7.0 native templates
2026-07-02 Add ASA print and calibration guide for Creality K1
2026-07-14 docs: update manual to EBB42 v1.2.1 and add toolhead sensor support models
    [suporte_sensor_ke.scad, suporte_sensor_ke.stl]
